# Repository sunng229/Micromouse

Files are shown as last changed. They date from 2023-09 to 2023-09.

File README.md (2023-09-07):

## Micromouse

An autonomous maze solving robot for the IEEE club at UCLA. The goal is to build and design a robot that autonomously navigates through a 16x16 maze to reach the center and back as fast as possible.

It accomplishes this using IR sensors to detect any walls, continously storing that data as it continues its path primarily using an algorithm called Floodfill, which is implemented in solver.c inside the Src folder.

Included are the following:
* Src folder: all the important source code  
* Inc folder: the H files for the C files
* the build/schematic files for the PCB

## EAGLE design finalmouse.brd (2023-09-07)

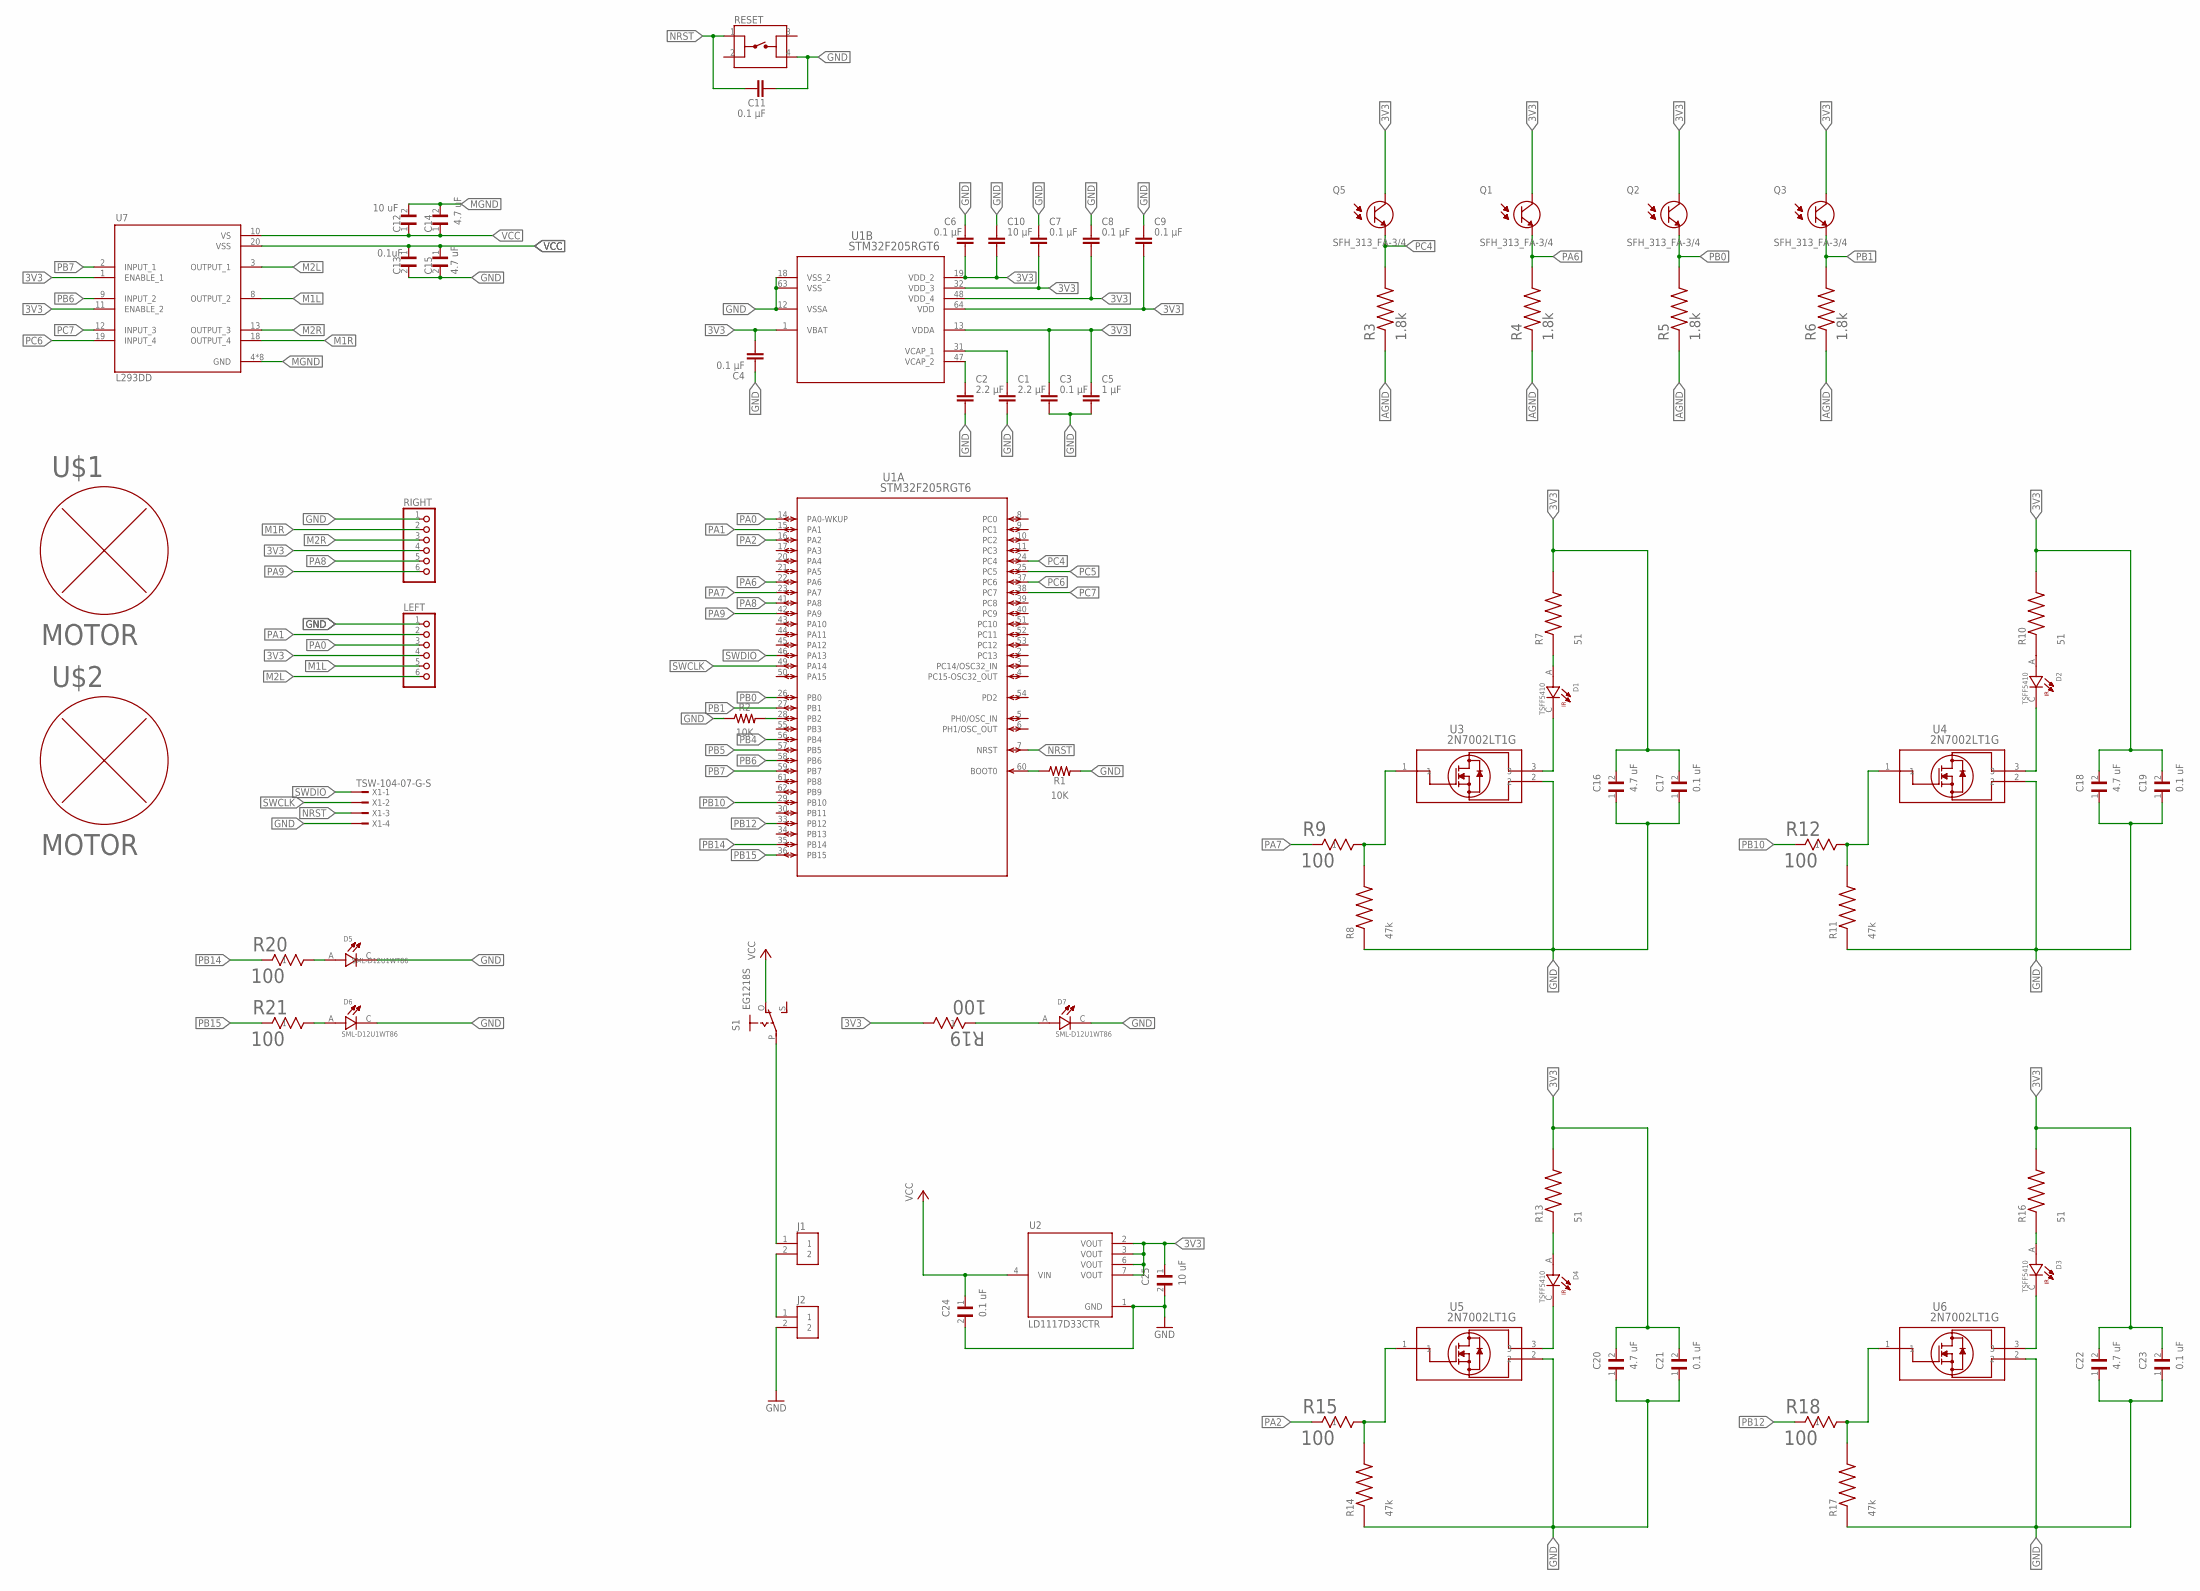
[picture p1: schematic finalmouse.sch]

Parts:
C1, C2: 2.2 μF; CAPC1608X85
C3, C4, C6, C7, C8, C9, C11: 0.1 μF; CAPC1608X85
C5: 1 μF; CAPC1608X85
C10: 10 μF; CAPC1608X85
C12, C25: 10 uF; CAPC2012X135N
C13: 0.1uF; CAPC2012X94N
C14, C15, C16, C18, C20, C22: 4.7 uF; CAPC2012X145N
C17, C19, C21, C23: 0.1 uF; CAPC2012X94N
C24: 0.1 uF; CAPC2012X135N
D1, D2, D3, D4: TSFF5410; LEDRD254W55D595H1160
D5, D6, D7: SML-D12U1WT86; LED_SML-D12Y1WT86
J1, J2: B2B-PH-K-S(LF)(SN); JST_B2B-PH-K-S(LF)(SN)
LEFT: PINHD-1X6; 1X06
Q1, Q2, Q3, Q5: SFH_313_FA-3/4; XDCR_SFH_313_FA-3/4
R1, R2: 10K; RESC1608X60
R3, R4, R5, R6: 1.8k; RESC2012X65N
R7, R10, R13, R16: 51; RES_ERJP06J510V
R8, R11, R14, R17: 47k; RES_ERA6ARB473V
R9, R12, R15, R18, R19, R20, R21: 100; RES_RK73G2A_KOA
RESET: FSM4JSMA; TE_FSM4JSMA
RIGHT: PINHD-1X6; 1X06
S1: EG1218S; EG1218
U1: STM32F205RGT6; LQFP64-10X10MM
U2: LD1117D33CTR; SOIC127P600X175-8N
U3, U4, U5, U6: 2N7002LT1G; SOT-23_3L_ONS
U7: L293DD; SOIC127P1032X265-20N
U$1, U$2: MOTOR
X1: TSW-104-07-G-S; TSW-104-XX-G-S

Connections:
3V3: C3.1, C4.2, C5.1, C6.2, C7.2, C8.2, C9.2, C10.2, C16.2, C17.2, C18.2, C19.2, C20.2, C21.2, C22.2, C23.2, C25.1, LEFT.4, Q1.2 (C), Q2.2 (C), Q3.2 (C), Q5.2 (C), R7.2, R10.2, R13.2, R16.2, R19.2, RIGHT.4, U1.1 (VBAT), U1.13 (VDDA), U1.19 (VDD_2), U1.32 (VDD_3), U1.48 (VDD_4), U1.64 (VDD), U2.2 (VOUT), U2.3 (VOUT), U2.6 (VOUT), U2.7 (VOUT), U7.1 (ENABLE_1), U7.11 (ENABLE_2)
AGND: R3.1, R4.1, R5.1, R6.1
GND: C1.2, C2.2, C3.2, C4.1, C5.2, C6.1, C7.1, C8.1, C9.1, C10.1, C11.2, C13.2, C15.2, C16.1, C17.1, C18.1, C19.1, C20.1, C21.1, C22.1, C23.1, C24.2, C25.2, D5.C, D6.C, D7.C, J2.2, LEFT.1, R1.2, R2.1, R8.1, R11.1, R14.1, R17.1, RESET.4, RIGHT.1, U1.12 (VSSA), U1.18 (VSS_2), U1.63 (VSS), U2.1 (GND), U3.2, U4.2, U5.2, U6.2, X1.4
M1L: LEFT.5, U7.8 (OUTPUT_2)
M1R: RIGHT.2, U7.18 (OUTPUT_4)
M2L: LEFT.6, U7.3 (OUTPUT_1)
M2R: RIGHT.3, U7.13 (OUTPUT_3)
MGND: C12.2, C14.2, U7.4 (GND), U7.5 (GND), U7.6 (GND), U7.7 (GND), U7.14 (GND), U7.15 (GND), U7.16 (GND), U7.17 (GND)
unnamed: C1.1, U1.31 (VCAP_1)
unnamed: C2.1, U1.47 (VCAP_2)
unnamed: R1.1, U1.60 (BOOT0)
unnamed: R2.2, U1.28 (PB2)
unnamed: J1.1, S1.P
unnamed: D1.A, R7.1
unnamed: R8.2, R9.2, U3.1
unnamed: D1.C, U3.3
unnamed: D2.A, R10.1
unnamed: R11.2, R12.2, U4.1
unnamed: D2.C, U4.3
unnamed: D3.A, R16.1
unnamed: R14.2, R15.2, U5.1
unnamed: D4.C, U5.3
unnamed: D4.A, R13.1
unnamed: R17.2, R18.2, U6.1
unnamed: D3.C, U6.3
unnamed: D7.A, R19.1
unnamed: J1.2, J2.1
unnamed: D5.A, R20.2
unnamed: D6.A, R21.2
NRST: C11.1, RESET.1, U1.7 (NRST), X1.3
PA0: LEFT.3, U1.14 (PA0-WKUP)
PA1: LEFT.2, U1.15 (PA1)
PA2: R15.1, U1.16 (PA2)
PA6: Q1.1 (E), R4.2, U1.22 (PA6)
PA7: R9.1, U1.23 (PA7)
PA8: RIGHT.5, U1.41 (PA8)
PA9: RIGHT.6, U1.42 (PA9)
PB0: Q2.1 (E), R5.2, U1.26 (PB0)
PB1: Q3.1 (E), R6.2, U1.27 (PB1)
PB4: U1.56 (PB4)
PB5: U1.57 (PB5)
PB6: U1.58 (PB6), U7.9 (INPUT_2)
PB7: U1.59 (PB7), U7.2 (INPUT_1)
PB10: R12.1, U1.29 (PB10)
PB12: R18.1, U1.33 (PB12)
PB14: R20.1, U1.35 (PB14)
PB15: R21.1, U1.36 (PB15)
PC4: Q5.1 (E), R3.2, U1.24 (PC4)
PC5: U1.25 (PC5)
PC6: U1.37 (PC6), U7.19 (INPUT_4)
PC7: U1.38 (PC7), U7.12 (INPUT_3)
SWCLK: U1.49 (PA14), X1.2
SWDIO: U1.46 (PA13), X1.1
VCC: C12.1, C13.1, C14.1, C15.1, C24.1, S1.O, U2.4 (VIN), U7.10 (VS), U7.20 (VSS)

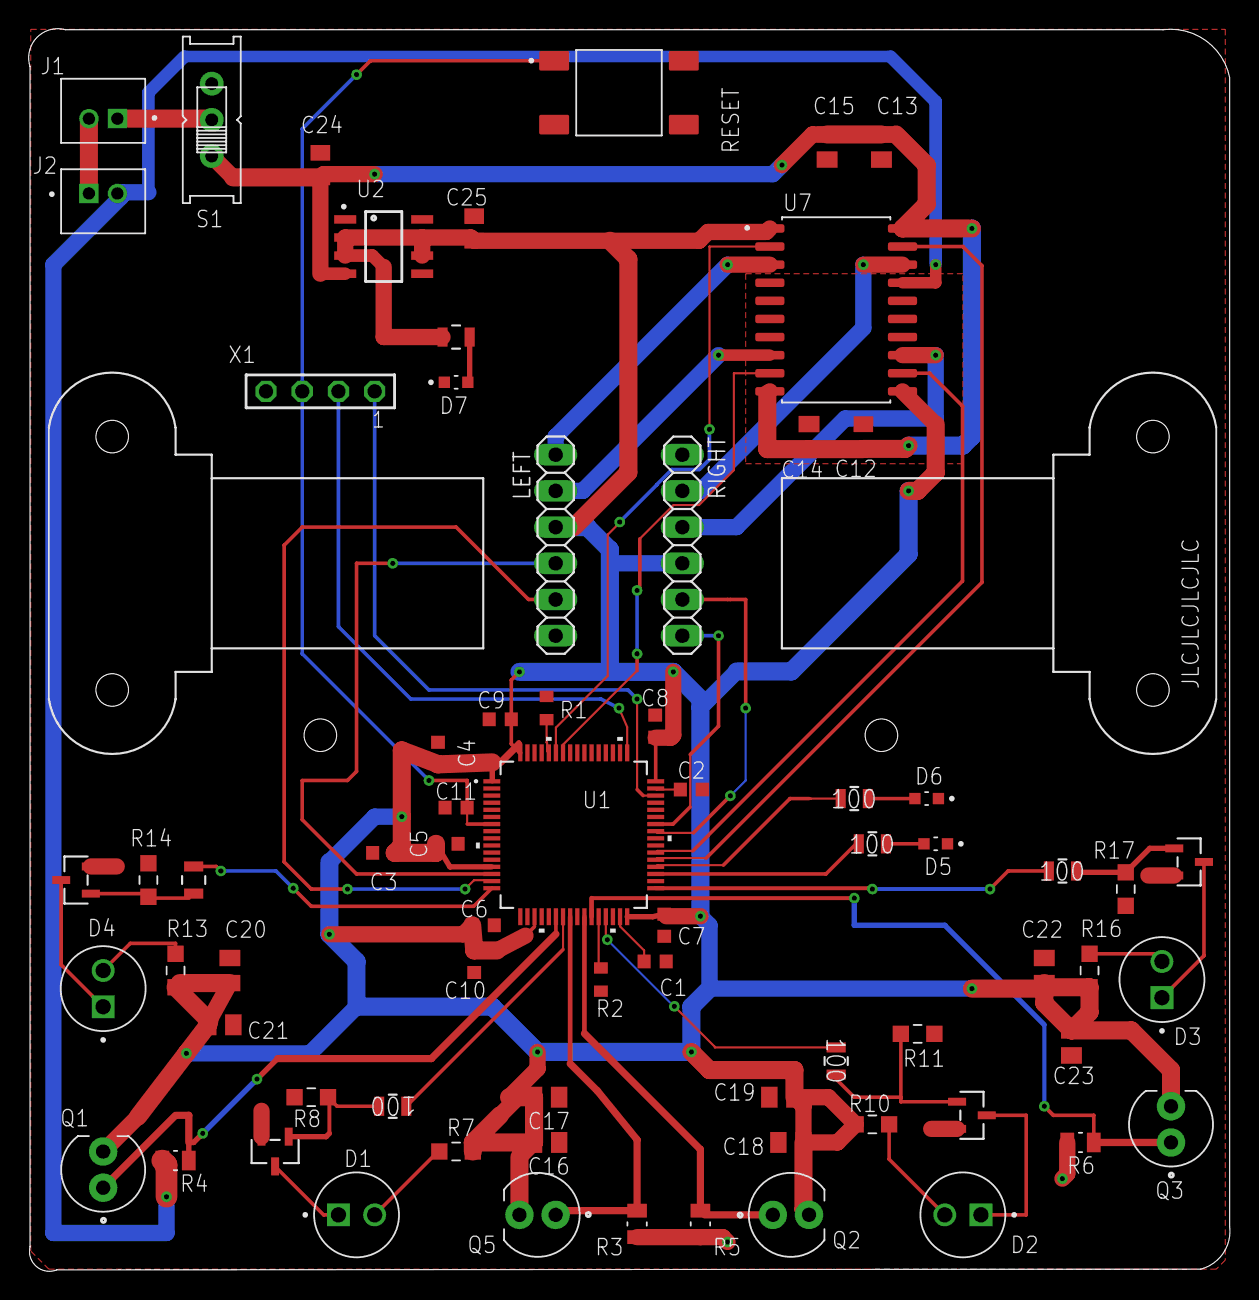
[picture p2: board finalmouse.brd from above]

Board: 2 copper layers, 84.3 x 87.2 mm, 73 parts (0 on the bottom side), 51 nets.

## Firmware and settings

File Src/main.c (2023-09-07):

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
/* Includes ------------------------------------------------------------------*/
#include "main.h"

/* USER CODE BEGIN Includes */
#include "motors.h"
#include "encoders.h"
#include "pid.h"
#include "controller.h"
#include "delay.h"
#include "irs.h"
#include "solver.h"
/* USER CODE END Includes */

ADC_HandleTypeDef hadc1;
DMA_HandleTypeDef hdma_adc1;

TIM_HandleTypeDef htim1;
TIM_HandleTypeDef htim2;
TIM_HandleTypeDef htim3;
TIM_HandleTypeDef htim4;

/* USER CODE BEGIN PV */
int16_t left_counts = 0;
int16_t right_counts = 0;
uint16_t front_right_receiver = 0;
uint16_t right_receiver = 0;
uint16_t front_left_receiver = 0;
uint16_t left_receiver = 0;
/* USER CODE END PV */

void SystemClock_Config(void);
static void MX_GPIO_Init(void);
static void MX_ADC1_Init(void);
static void MX_TIM1_Init(void);
static void MX_TIM2_Init(void);
static void MX_TIM3_Init(void);
static void MX_DMA_Init(void);
static void MX_TIM4_Init(void);
/**
  * @brief  The application entry point.
  * @retval int
  */
int main(void)
{
  /* MCU Configuration--------------------------------------------------------*/

  /* Reset of all peripherals, Initializes the Flash interface and the Systick. */
  HAL_Init();

  /* USER CODE BEGIN Init */
	Delay_Init();
  /* USER CODE END Init */

  /* Configure the system clock */
  SystemClock_Config();

  /* Initialize all configured peripherals */
  MX_GPIO_Init();
  MX_DMA_Init();
  MX_TIM1_Init();
  MX_TIM2_Init();
  MX_TIM3_Init();
  MX_ADC1_Init();
  MX_TIM4_Init();
  /* USER CODE BEGIN 2 */
	//HAL_ADC_Start(&hadc1);
	//encoders
	HAL_TIM_Encoder_Start(&htim1, TIM_CHANNEL_ALL);
	HAL_TIM_Encoder_Start(&htim2, TIM_CHANNEL_ALL);

	//motors
	HAL_TIM_PWM_Start(&htim3, TIM_CHANNEL_1);
	HAL_TIM_PWM_Start(&htim3, TIM_CHANNEL_2);
	HAL_TIM_PWM_Start(&htim4, TIM_CHANNEL_1);
	HAL_TIM_PWM_Start(&htim4, TIM_CHANNEL_2);

  /* USER CODE END 2 */

  /* Infinite loop */
  /* USER CODE BEGIN WHILE */

	HAL_Delay(1000);
	HAL_GPIO_WritePin(LED1_GPIO_Port, LED1_Pin, GPIO_PIN_SET);
	HAL_Delay(1000);
	HAL_GPIO_WritePin(LED1_GPIO_Port, LED1_Pin, GPIO_PIN_RESET);
	HAL_Delay(1000);
	while (1) {
		/*
		 front_right_receiver = readFrontRightIR();
		 left_receiver = readRightIR(); // > 3000 too close to wall
		 front_left_receiver = readFrontLeftIR();
		 right_receiver = readLeftIR();  // > 3000 too close to wall

		 if (front_right_receiver > 700 || front_left_receiver > 700) {
		 	  turn(1);
		 }
		 else {;
		   move(1);
		 }
		 left_counts = -getLeftEncoderCounts();
		 right_counts = -getRightEncoderCounts();
*/

		Action nextMove = solver();
		switch (nextMove) {
		case FORWARD:
			move(1);
			HAL_Delay(250);
			break;
		case LEFT:
			turn(-1);

			break;
		case RIGHT:
			turn(1);

			break;
		case TURNAROUND:
			turn(2);

			break;
		case IDLE:
			break;
}

			//move(1);

    /* USER CODE END WHILE */

}
}

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
/* USER CODE BEGIN 4 */
	ADC_HandleTypeDef* Get_HADC1_Ptr(void) {
		return &hadc1;
	}

/* USER CODE END 4 */
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


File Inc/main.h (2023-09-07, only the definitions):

#define LeftEncoderCh1_Pin GPIO_PIN_0
#define LeftEncoderCh1_GPIO_Port GPIOA
#define LeftEnconderCh2_Pin GPIO_PIN_1
#define LeftEnconderCh2_GPIO_Port GPIOA
#define LeftEmitter_Pin GPIO_PIN_2
#define LeftEmitter_GPIO_Port GPIOA
#define LeftReceiver_Pin GPIO_PIN_6
#define LeftReceiver_GPIO_Port GPIOA
#define FrontLeftEmitter_Pin GPIO_PIN_7
#define FrontLeftEmitter_GPIO_Port GPIOA
#define FrontLeftReceiver_Pin GPIO_PIN_4
#define FrontLeftReceiver_GPIO_Port GPIOC
#define FrontRightReceiver_Pin GPIO_PIN_0
#define FrontRightReceiver_GPIO_Port GPIOB
#define RightReceiver_Pin GPIO_PIN_1
#define RightReceiver_GPIO_Port GPIOB
#define FrontRightEmitter_Pin GPIO_PIN_10
#define FrontRightEmitter_GPIO_Port GPIOB
#define RightEmitter_Pin GPIO_PIN_12
#define RightEmitter_GPIO_Port GPIOB
#define LED1_Pin GPIO_PIN_14
#define LED1_GPIO_Port GPIOB
#define LED2_Pin GPIO_PIN_15
#define LED2_GPIO_Port GPIOB
#define M1R_Pin GPIO_PIN_6
#define M1R_GPIO_Port GPIOC
#define M2R_Pin GPIO_PIN_7
#define M2R_GPIO_Port GPIOC
#define RightEncoderCh1_Pin GPIO_PIN_8
#define RightEncoderCh1_GPIO_Port GPIOA
#define RightEncoderCh2_Pin GPIO_PIN_9
#define RightEncoderCh2_GPIO_Port GPIOA
#define M1L_Pin GPIO_PIN_6
#define M1L_GPIO_Port GPIOB
#define M2L_Pin GPIO_PIN_7
#define M2L_GPIO_Port GPIOB

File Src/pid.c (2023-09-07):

/*
 * pid.c
 */

#include "main.h"
#include "motors.h"
#include "encoders.h"
int angleError = 0;
int oldAngleError = 0;
float distanceError = (0.4);
float oldDistanceError = 0;
float angleCorrection = 0;
float distanceCorrection = 0;
float kPw = (.02); //0.23
float kDw = (0.3); //0
float kPx = (.002); //0.0018
float kDx = (.005); //0
int goalAngle = 0;
int goalDistance = 0;
int done = 0;
int done2 = 0;
void resetPID() {
	/*
	 * For assignment 3.1: This function does not need to do anything
	 * For assignment 3.2: This function should reset all the variables you define in this file to help with PID to their default
	 *  values. You should also reset your motors and encoder counts (if you tell your rat to turn 90 degrees, there will be a big
	 * difference in encoder counts after it turns. If you follow that by telling your rat to drive straight without first
	 * resetting the encoder counts, your rat is going to see a huge angle error and be very unhappy).
	 *
	 * You should additionally set your distance and error goal values (and your oldDistanceError and oldAngleError) to zero.
	 */
	 angleError = 0;
	 oldAngleError = 0;
	 distanceError = 0;
	 oldDistanceError = 0;
	 //kPw = (0.03);
	 //kDw = (0);
	 //kPx = 1;
	 //kDx = (0.5);
	 goalAngle = 0;
	 goalDistance = 0;
	 done = 0;
	 resetEncoders();
	 done2 = 0;
	 resetMotors();
}

void updatePID() {
	/*
	 * This function will do the heavy lifting PID logic. It should do the following: read the encoder counts to determine an error,
	 * use that error along with some PD constants you determine in order to determine how to set the motor speeds, and then actually
	 * set the motor speeds.
	 *
	 * For assignment 3.1: implement this function to get your rat to drive forwards indefinitely in a straight line. Refer to pseudocode
	 * example document on the google drive for some pointers
	 *
	 * TIPS (assignment 3.1): Create kPw and kDw variables, use a variable to store the previous error for use in computing your
	 * derivative term. You may get better performance by having your kDw term average the previous handful of error values instead of the
	 * immediately previous one, or using a stored error from 10-15 cycles ago (stored in an array?). This is because systick calls so frequently
	 * that the error change may be very small and hard to operate on.
	 *
	 * For assignment 3.2: implement this function so it calculates distanceError as the difference between your goal distance and the average of
	 * your left and right encoder counts. Calculate angleError as the difference between your goal angle and the difference between your left and
	 * right encoder counts. Refer to pseudocode example document on the google drive for some pointers.
	 */
	int left_receiverr = get_left_receiver();
	int right_receiverr = get_right_receiver();
	int adjust = 0;
if(!get_turn_status()){
	if(left_receiverr > 1000 && right_receiverr > 1000) {
							adjust = left_receiverr - right_receiverr;
							adjust = adjust/95;
							if(adjust < 15)
								adjust = 0;
							setPIDGoalA(adjust);
						}
			else if(left_receiverr > 2900){ //3000
				adjust = (left_receiverr/100); //110
				if(adjust < 15)
					adjust = 0;
				setPIDGoalA(adjust);
			}
			else if(right_receiverr > 2900)//3000
			{
				adjust=-(right_receiverr/100); //110
				if(adjust < 15)
					adjust = 0;
				setPIDGoalA(adjust);
			}
}
		angleError = goalAngle + (-(getRightEncoderCounts()*0.9995) + getLeftEncoderCounts());
	angleCorrection = kPw * angleError + kDw * (angleError - oldAngleError);
		oldAngleError = angleError;


		distanceError = goalDistance + ((-getLeftEncoderCounts() - getRightEncoderCounts())/2);
	distanceCorrection = kPx * distanceError + kDx * (distanceError - oldDistanceError);
		oldDistanceError = distanceError;

		if(distanceCorrection > 0.25 ) {
			distanceCorrection = 0.25;
		}
		if(angleCorrection > 0.25) {
			angleCorrection = 0.25;
		}
		else if(angleCorrection < -0.25) {
			angleCorrection = -0.25;
		}

	setMotorLPWM((distanceCorrection - angleCorrection));
	setMotorRPWM((distanceCorrection + angleCorrection));

	if(angleError < 8 && angleError > -8){	done++;}
	if(distanceError < 75 && distanceError > -75){	done2++;}

		/*
		Since the goal of this assignment is to go forwards indefinitely, we just set the distanceError to
		some arbitrary value. Since the error is fixed, distanceCorrection will always equal kPx times
		whatever value you set distanceError to be. If you follow the suggested values and set kPx equal
		to 1 and distance error to 0.4, your motors will have an effecitve base speed of 0.4. The derivative
		term will always be zero since the distanceError doesn't change.

		PD control is implemented in the angleCorrection line, and this adjustment is added (or subtracted)
		from each motor, depending on what you treat as your positive angle direction. In the next assignment,
		you will dynamically set distanceError based on encoder counts in order to move fixed distances.
		*/
}

void setPIDGoalD(int16_t distance) {
	/*
	 * For assignment 3.1: this function does not need to do anything.
	 * For assignment 3.2: this function should set a variable that stores the goal distance.
	 */
	goalDistance = distance;
	done = 0;
	done2 = 0;

}

void setPIDGoalA(int16_t angle) {
	/*
	 * For assignment 3.1: this function does not need to do anything
	 * For assignment 3.2: This function should set a variable that stores the goal angle.
	 */
	goalAngle = angle;
	done = 0;
	done2 = 0;
}

int8_t PIDdone(void) { // There is no bool type in C. True/False values are represented as 1 or 0.
	/*
	 * For assignment 3.1: this function does not need to do anything (your rat should just drive straight indefinitely)
	 * For assignment 3.2:This function should return true if the rat has achieved the set goal. One way to do this by having updatePID() set some variable when
	 * the error is zero (realistically, have it set the variable when the error is close to zero, not just exactly zero). You will have better results if you make
	 * PIDdone() return true only if the error has been sufficiently close to zero for a certain number, say, 50, of SysTick calls in a row.
	 */

    return (done) && (done2);
}

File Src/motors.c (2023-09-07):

/*
 * motors.c
 */

#include "motors.h"

/*
 * This function should return PWM_MAX if pwm > PWM_MAX, -PWM_MAX if pwm < -PWM_MAX, and pwm otherwise.
 */
float limitPWM(float pwm) {
	if (pwm > PWM_MAX) {
		return PWM_MAX;
	}
	else if (pwm < -PWM_MAX) {
		return -PWM_MAX;
	}
	else {
		return pwm;
		}
	}

/*
 * This function controls the left motor speed and direction. We do this by setting the timer pulse value for the appropriate channel.
 * All our H-bridge inputs use timer 4. TIM4->CCRX = (uint32_t) (limitPWM(pwm) * MAX_TIMER_COUNTS) sets the pulse value for channel x.
 * For the left motor, setting channel 3 makes the wheel spin forward and setting channel 4 makes the wheel spin backwards.
 *
 * The parameter pwm is a value between 0 and 1, representing the percentage of maximum speed to turn the motor. e.g. 0.5 is half speed.
 *
 * IMPORTANT: NEVER SET BOTH THE FORWARD AND BACKWARD CHANNELS TO NON-ZERO VALUES AT THE SAME TIME. As mentioned in lecture, this can
 * destroy your h-bridge. When setting a channel, always set the other channel to zero first.
 *
 * Implement this function to make the left wheel spin forwards when pwm is >= 0, and spin backwards when pwm < 0.
 */

//uses timer 4, ch1 and ch2
void setMotorLPWM(float pwm) {
	if (pwm < 0) { //backwards
		TIM4->CCR1 = (uint32_t) -(limitPWM(pwm) * MAX_TIMER_COUNTS);
		TIM4->CCR2 = 0;
	}
	else { //forwards
		TIM4->CCR2 = (uint32_t) (limitPWM(pwm) * MAX_TIMER_COUNTS);
		TIM4->CCR1 = 0;

	}
}

/*
 * This function controls the right motor speed and direction. We do this by setting the timer pulse value for the appropriate channel.
 * All our H-bridge inputs use timer 4. TIM4->CCRX = (uint32_t) (limitPWM(pwm) * MAX_TIMER_COUNTS) sets the pulse value for channel x.
 * For the right motor, setting channel 1 makes the wheel spin forward and setting channel 2 makes the wheel spin backwards.
 *
 * The parameter pwm is a value between 0 and 1, representing the percentage of maximum speed to turn the motor. e.g. 0.5 is half speed.
 *
 * IMPORTANT: NEVER SET BOTH THE FORWARD AND BACKWARD CHANNELS TO NON-ZERO VALUES AT THE SAME TIME. As mentioned in lecture, this can
 * destroy your h-bridge. When setting a channel, always set the other channel to zero first.
 *
 * Implement this function to make the right wheel spin forwards when pwm is >= 0, and spin backwards when pwm < 0.
 */

//uses timer 3, ch1 and ch2
void setMotorRPWM(float pwm) {
	if (pwm>=0) { //forwards
	TIM3->CCR1 = (uint32_t) (limitPWM(pwm) * MAX_TIMER_COUNTS);
	TIM3->CCR2 = 0;
	}
	else { //backwards
		TIM3->CCR2 = (uint32_t) -(limitPWM(pwm) * MAX_TIMER_COUNTS);
		TIM3->CCR1 = 0;
	}
}

/*
 * Using the two previous setMotorPWM functions, implement resetMotors to set the PWM for both wheels to zero, effectively stopping them.
 */
void resetMotors() {
	setMotorRPWM(0);
	setMotorLPWM(0);
}

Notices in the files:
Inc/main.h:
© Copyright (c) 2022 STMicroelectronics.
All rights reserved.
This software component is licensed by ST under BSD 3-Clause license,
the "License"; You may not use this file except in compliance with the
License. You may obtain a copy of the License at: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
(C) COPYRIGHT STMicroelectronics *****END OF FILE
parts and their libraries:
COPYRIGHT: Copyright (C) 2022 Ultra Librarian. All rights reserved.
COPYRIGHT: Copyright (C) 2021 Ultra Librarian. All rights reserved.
